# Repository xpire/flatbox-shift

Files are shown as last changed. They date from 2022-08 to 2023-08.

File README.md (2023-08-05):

# Hotbox: Low profile hitbox-layout fightstick
## This is a fork of Flatbox, where the PCB was modified to have a shift along with the directional inputs, and use hotswappable fullsize MX key switches

This repository contains 3D-printable models, PCB design files and code needed to make an arcade controller that looks like this:

Assembled Flatbox Shift
Look at the table for the difference between each revision.

Reddit post: https://www.reddit.com/r/fightsticks/comments/y1vh9n/my_custom_fight_stick_made_with_a_custom_pcb_7/

version | [rev1.1](hardware-rev1.1) | [rev2](hardware-rev2) | [rev3](hardware-rev3) | [rev4](hardware-rev4) | [shift](hardware-shift-rev2)
------- | ------------------------- | --------------------- | --------------------- | --------------------- | ----
case dimensions | 218x128x10mm | 218x130x10mm | 218x130x10mm | 218x130x10mm | 227.14x120x?mm
compatibility (using provided firmware) | PC, PS3 | PC, PS3 | PC, PS3, PS4 | PC, PS3 | PC, PS3
add-on board | Arduino Pro Micro | - | [Brook PS3/PS4](https://www.brookaccessory.com/detail/58690501/) | - | Arduino Pro Micro
onboard chip | - | ATmega32U4 | - | RP2040 | - 
port | micro USB | USB-C | USB-C | USB-C | USB-C (there are pro micros with usb c)
SMT assembly required | no | yes | yes | yes | no
firmware | [ATmega32U4](firmware-atmega32u4) | [ATmega32U4](firmware-atmega32u4) | [Brook](https://www.brookaccessory.com/download/PS3/) | [RP2040](firmware-rp2040) | [ATmega32U4](firmware-atmega32u4)
shift key | no | no | no | no | ***yes!***
key switches | low profile | low profile | low profile | low profile | ***normal MX***
hot swappable | yes | yes | yes | yes | yes
solder-able | yes | yes | yes | yes | no

# Process

## Design and Planning

First, we used Kicad to edit this existing PCB layout, adding an extra button for shift and swapping out the low profile gaterons for full sized MX hotswap.

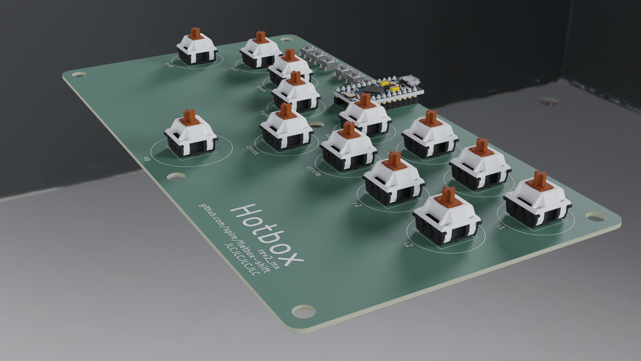
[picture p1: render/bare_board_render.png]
PCB Render


We then designed acrylic layers to encase the PCB, and mocked it in blender to see if it would work out.

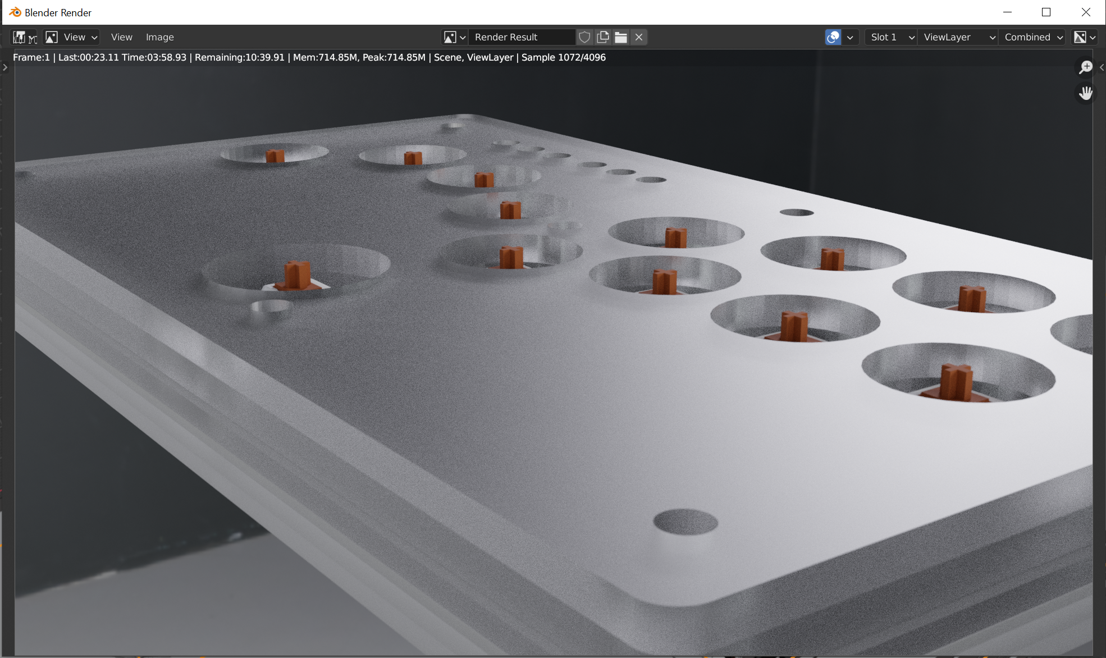
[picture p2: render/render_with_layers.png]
Acrylic Layers Render


## Prototyping

We printed the boards with https://jlcpcb.com/

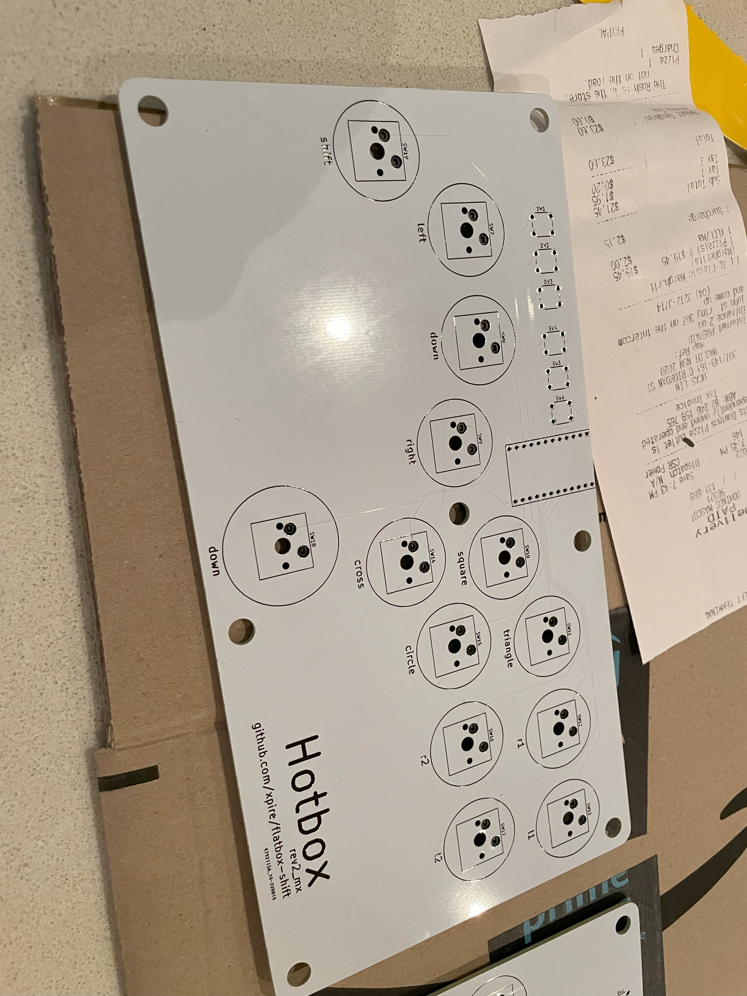
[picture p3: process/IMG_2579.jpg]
PCB IRL


We soldered on the arduino, and tested that the inputs worked

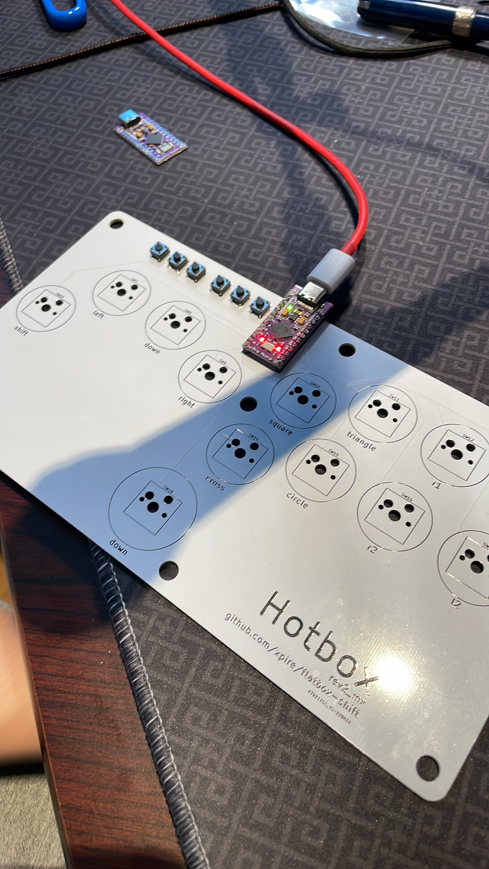
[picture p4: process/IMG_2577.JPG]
first test


Once we had verified the board worked, we 3D printed the layers to simulate what the final product would look like.

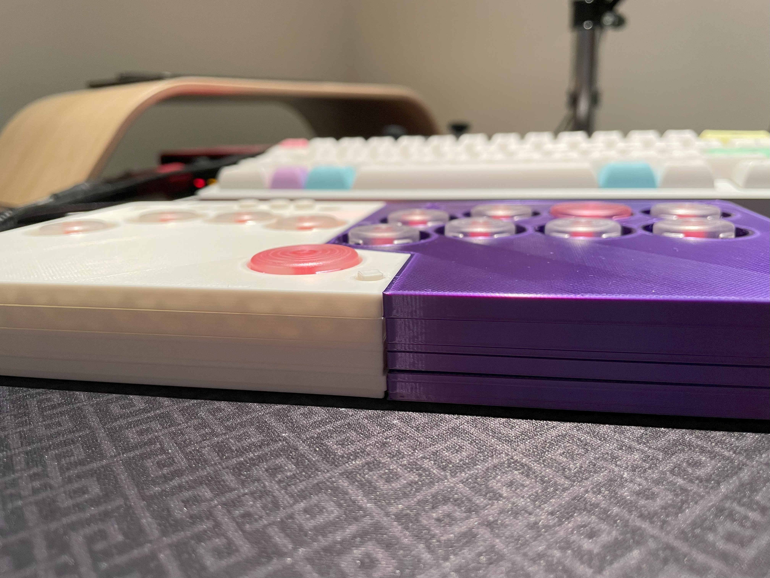
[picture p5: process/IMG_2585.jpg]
3d printed


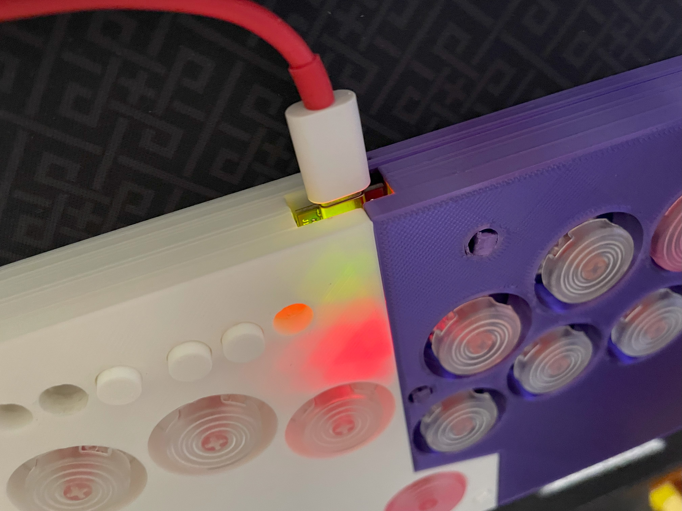
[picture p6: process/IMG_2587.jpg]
3d printed 2


## Fabrication

We borrowed a friend's uncle's CNC machine, and started carving the design out of sheets of acrylic.

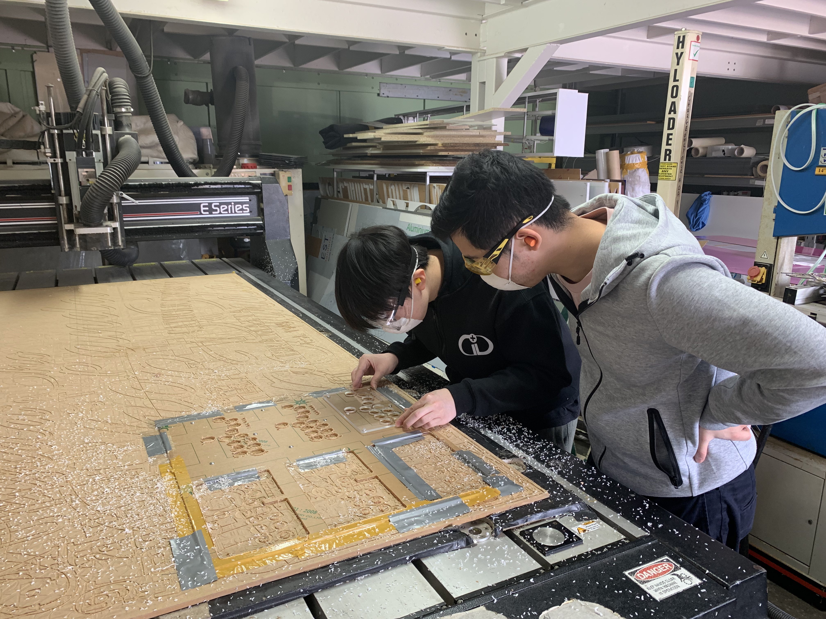
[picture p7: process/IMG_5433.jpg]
CNC 1


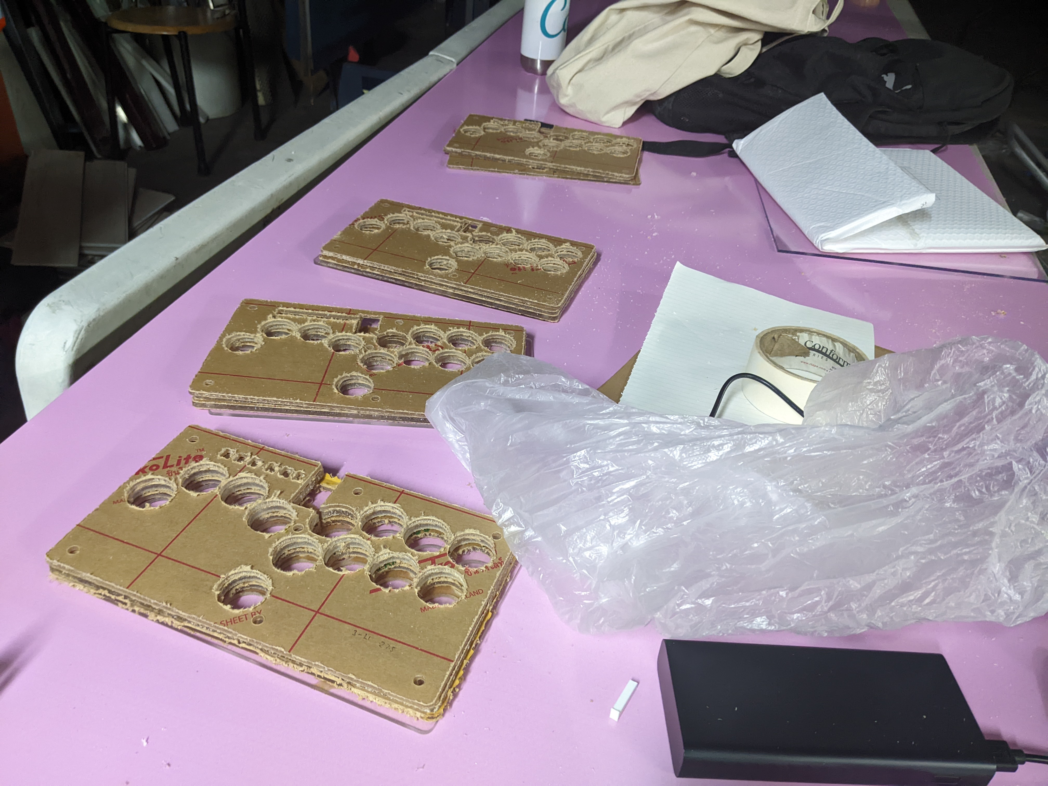
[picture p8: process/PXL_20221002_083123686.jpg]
CNC 2


## Result

front
Back
side
back2
stickers1
stickers2
stickers3

## Parts List
* arcade MX buttons - https://www.ebay.com/itm/165134564232 (url is now https://www.ebay.com/itm/155628299989)
* Chicago Screws - https://www.ebay.com/itm/0-67-034-to-0-87-034-17mm-to-22-mm-x-5mm-Stainless-steel-Knife-Handle-chicago-Screw-/231976520482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
* MX Switches
* Gateron hotswaps
* mini buttons
* Arduino pro micro with usb c
* Acrylic Layers (laser cut, or CNCed)

## Useful guides
- https://github.com/b1nc/Egg-On-Rice-Controller
- https://www.youtube.com/watch?v=ia2n7P3Csac

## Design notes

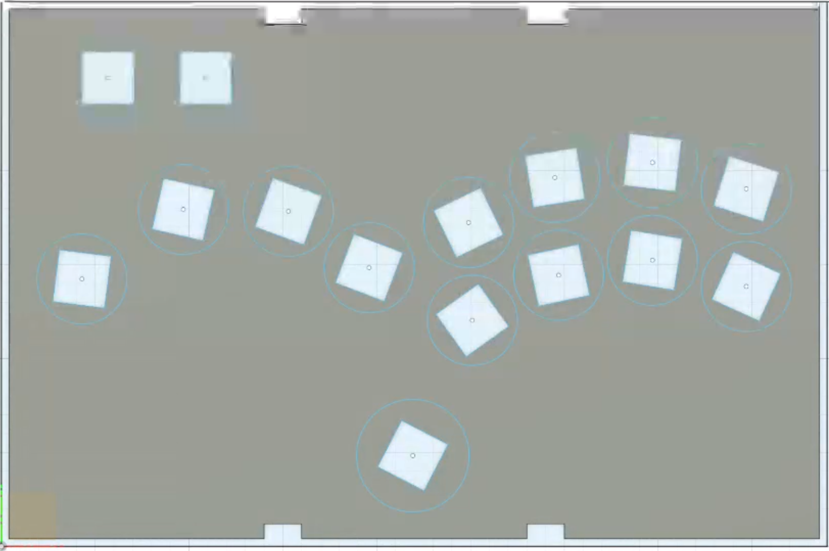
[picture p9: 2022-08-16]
hardware-shift-rev2/images/rough sketch.png

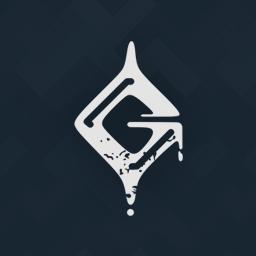
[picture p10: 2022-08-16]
hardware-shift-rev2/images/strive.jpg

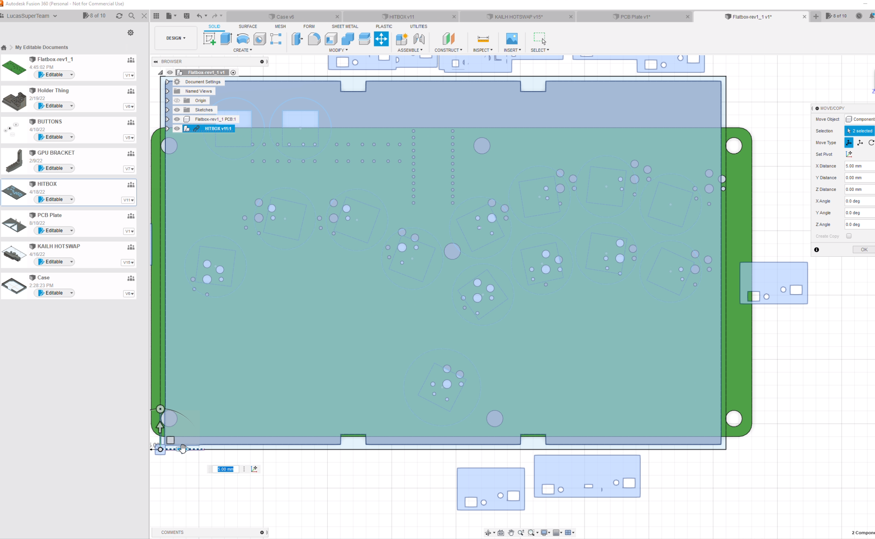
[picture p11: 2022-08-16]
hardware-shift-rev2/images/lucas vs current.png

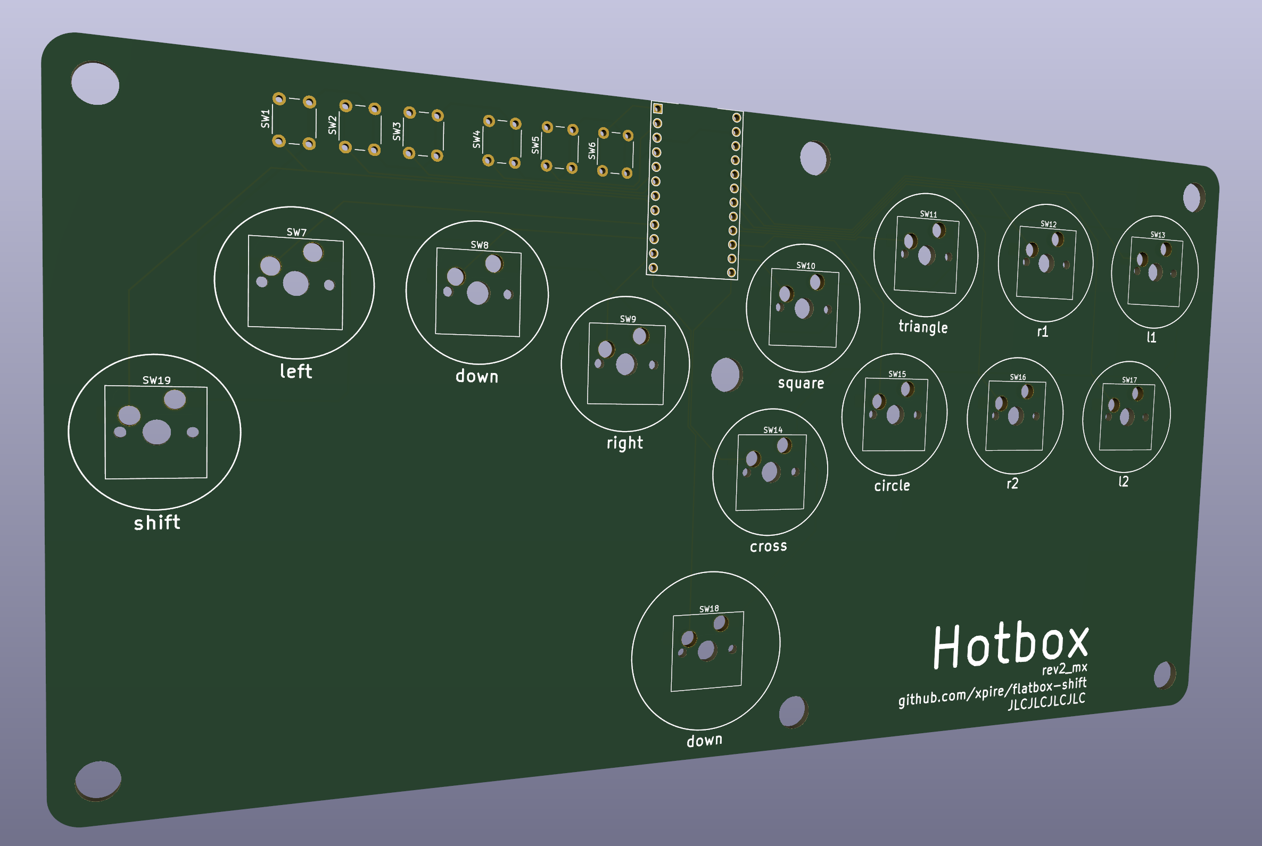
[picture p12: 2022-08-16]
hardware-shift-rev2/images/reference_pic.png

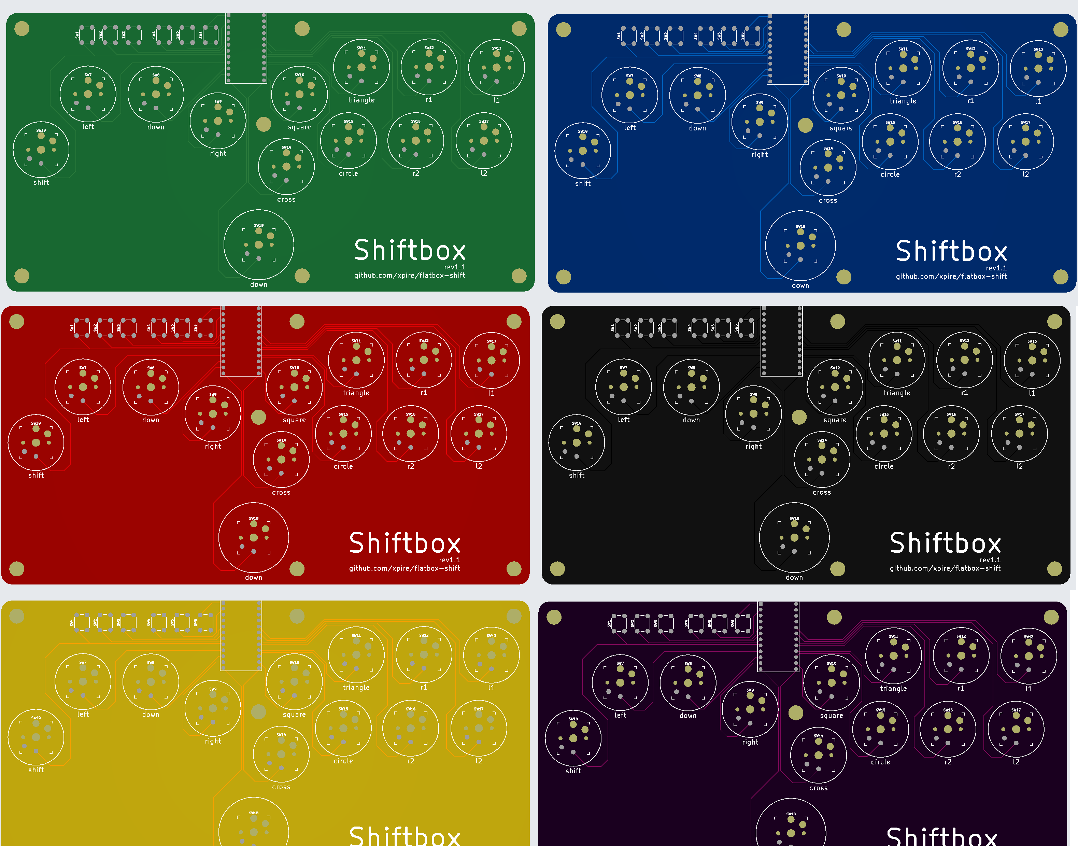
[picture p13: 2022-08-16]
hardware-shift-rev2/images/colorways.png

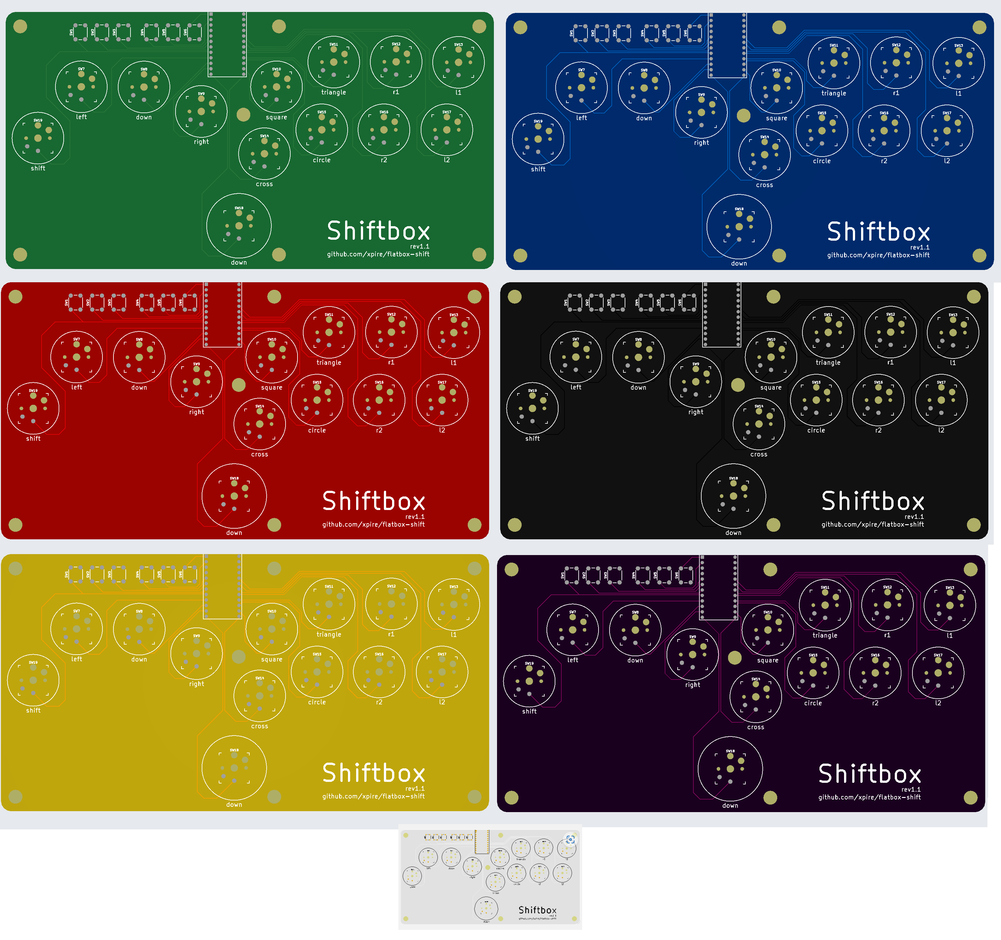
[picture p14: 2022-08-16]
hardware-shift-rev2/images/colorways-fixed.png

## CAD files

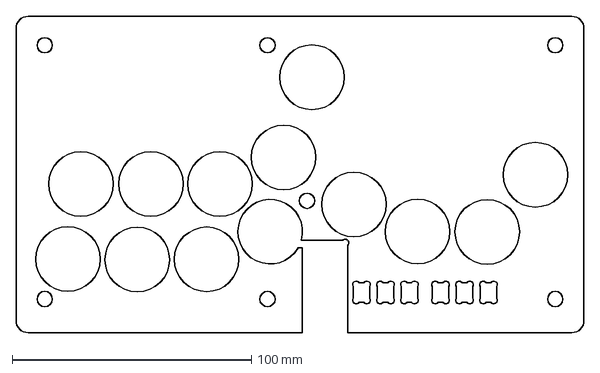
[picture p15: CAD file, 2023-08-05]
hardware-shift-rev2/acrylic/3_4.5mm.dxf
237.1 x 132.0 mm

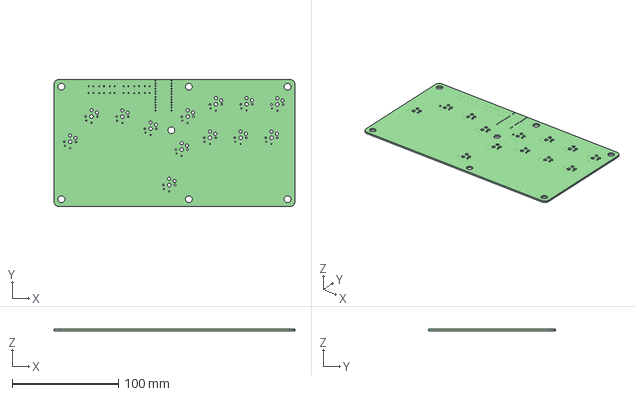
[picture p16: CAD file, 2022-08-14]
hardware-shift-rev2/extras/Flatbox-rev1.1-kicad/Flatbox-rev1_1.step
227.1 x 120.0 x 1.60 mm

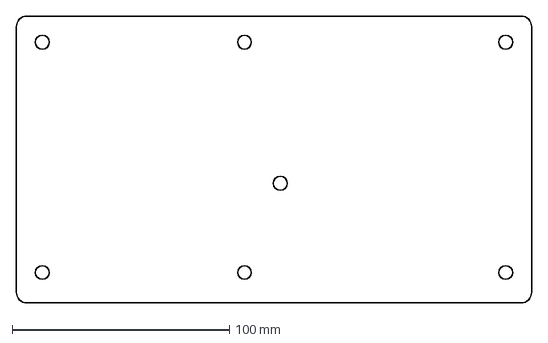
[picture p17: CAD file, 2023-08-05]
hardware-shift-rev2/acrylic/-2_1.5mm.dxf
237.1 x 132.0 mm

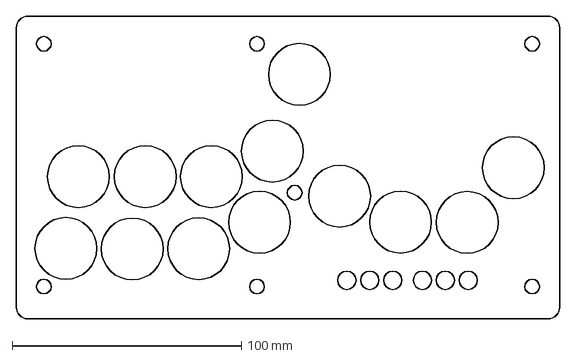
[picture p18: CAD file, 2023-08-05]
hardware-shift-rev2/acrylic/4_4.5mm.dxf
237.1 x 132.0 mm

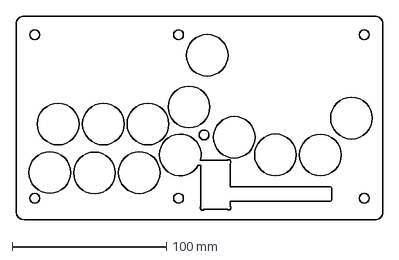
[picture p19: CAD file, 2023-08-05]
hardware-shift-rev2/acrylic/-1_3mm.dxf
237.1 x 132.0 mm

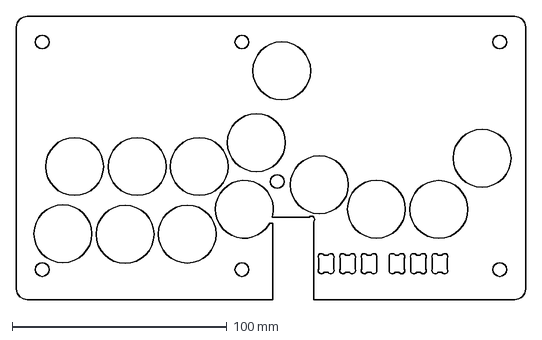
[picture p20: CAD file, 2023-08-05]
hardware-shift-rev2/acrylic/1_3.5mm.dxf
237.1 x 132.0 mm

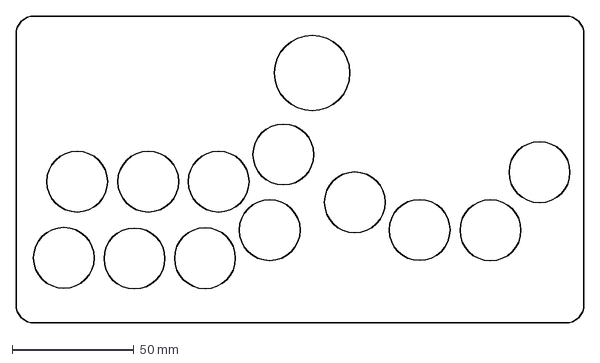
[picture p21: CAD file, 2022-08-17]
hardware-shift-rev2/acrylic/layer1.dxf
233.1 x 126.0 mm

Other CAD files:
hardware-shift-rev2/extras/Flatbox-rev2_mx.step

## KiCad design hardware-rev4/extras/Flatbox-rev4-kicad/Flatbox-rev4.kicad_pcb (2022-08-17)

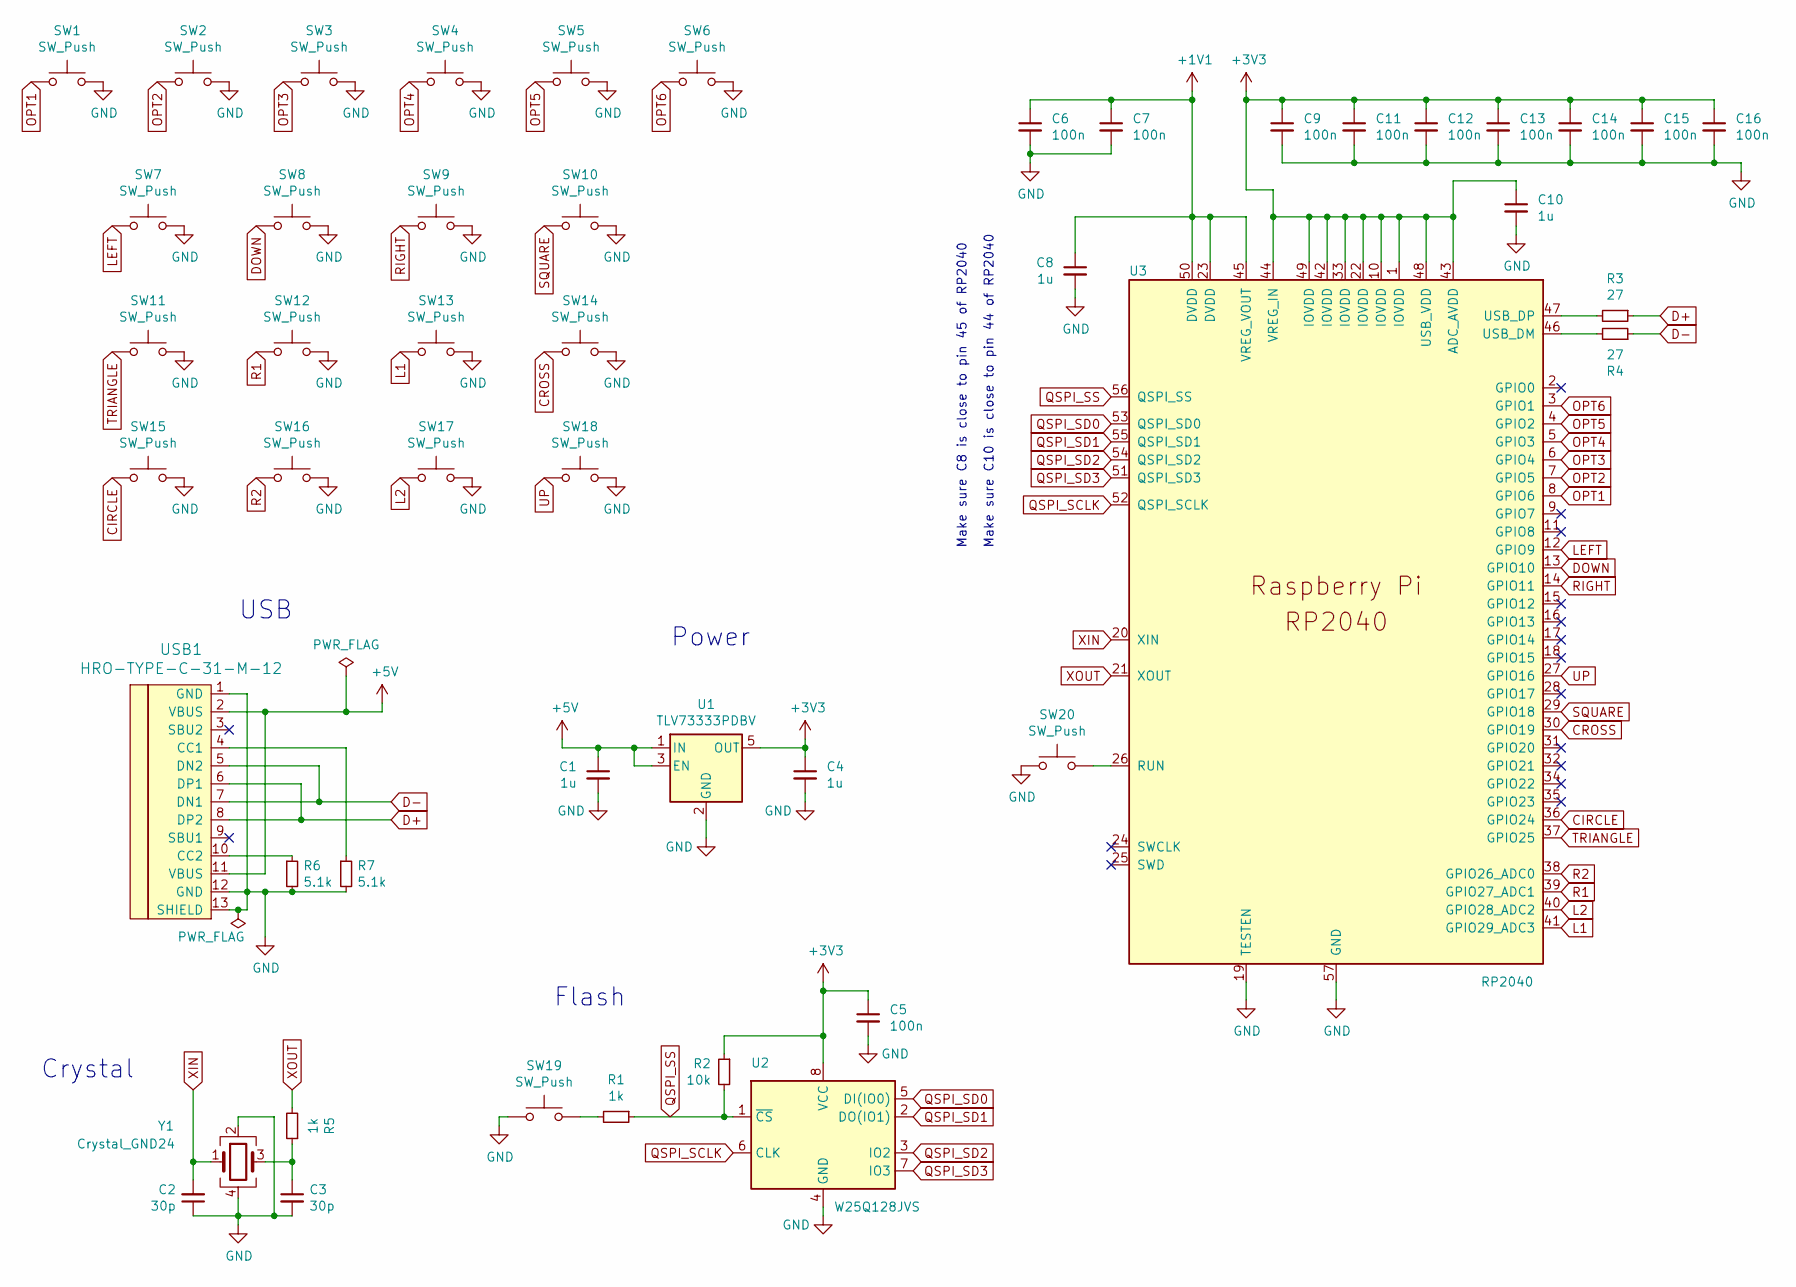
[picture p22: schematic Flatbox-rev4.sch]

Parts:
C1, C4, C8, C10: 1u; C_0402_1005Metric; LCSC C52923
C2, C3: 30p; C_0402_1005Metric; LCSC C1570
C5, C6, C7, C9, C11, C12, C13, C14, C15, C16: 100n; C_0402_1005Metric; LCSC C1525
R1, R5: 1k; R_0402_1005Metric; LCSC C11702
R2: 10k; R_0402_1005Metric; LCSC C25744
R3, R4: 27; R_0402_1005Metric; LCSC C138021
R6, R7: 5.1k; R_0402_1005Metric; LCSC C25905
SW1, SW2, SW3, SW4, SW5, SW6: SW_Push; SW_PUSH_6mm_H5mm
SW7, SW8, SW9, SW10, SW11, SW12, SW13, SW14, SW15, SW16, SW17, SW18: SW_Push; Kailh_socket_PG1350_optional
SW19, SW20: SW_Push; SW_SPST_Omron_B3FS-100xP; LCSC C271750
U1: TLV73333PDBV; SOT-23-5; LCSC C134139
U2: W25Q128JVS; SOIC-8_5.23x5.23mm_P1.27mm; LCSC C97521
U3: RP2040; RP2040-QFN-56; LCSC C2040
USB1: HRO-TYPE-C-31-M-12; HRO-TYPE-C-31-M-12-Assembly; LCSC C165948
Y1: Crystal_GND24; Crystal_SMD_3225-4Pin_3.2x2.5mm; LCSC C9002

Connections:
+1V1: C6.1, C7.1, C8.1, U3.23 (DVDD), U3.45 (VREG_VOUT), U3.50 (DVDD)
+3V3: C4.1, C5.1, C9.1, C10.1, C11.1, C12.1, C13.1, C14.1, C15.1, C16.1, R2.1, U1.5 (OUT), U2.8 (VCC), U3.1 (IOVDD), U3.10 (IOVDD), U3.22 (IOVDD), U3.33 (IOVDD), U3.42 (IOVDD), U3.43 (ADC_AVDD), U3.44 (VREG_IN), U3.48 (USB_VDD), U3.49 (IOVDD)
+5V: C1.1, U1.1 (IN), U1.3 (EN), USB1.2 (VBUS), USB1.11 (VBUS)
CIRCLE: SW15.1, U3.36 (GPIO24)
CROSS: SW14.1, U3.30 (GPIO19)
D+: R3.1, USB1.6 (DP1), USB1.8 (DP2)
D-: R4.1, USB1.5 (DN2), USB1.7 (DN1)
DOWN: SW8.1, U3.13 (GPIO10)
GND: C1.2, C2.1, C3.2, C4.2, C5.2, C6.2, C7.2, C8.2, C9.2, C10.2, C11.2, C12.2, C13.2, C14.2, C15.2, C16.2, R6.2, R7.2, SW1.2, SW2.2, SW3.2, SW4.2, SW5.2, SW6.2, SW7.2, SW8.2, SW9.2, SW10.2, SW11.2, SW12.2, SW13.2, SW14.2, SW15.2, SW16.2, SW17.2, SW18.2, SW19.1, SW20.1, U1.2 (GND), U2.4 (GND), U3.19 (TESTEN), U3.57 (GND), USB1.1 (GND), USB1.12 (GND), USB1.13 (SHIELD), Y1.2, Y1.4
L1: SW13.1, U3.41 (GPIO29_ADC3)
L2: SW17.1, U3.40 (GPIO28_ADC2)
LEFT: SW7.1, U3.12 (GPIO9)
unnamed: C3.1, R5.1, Y1.3
unnamed: R1.2, SW19.2
unnamed: R3.2, U3.47 (USB_DP)
unnamed: R4.2, U3.46 (USB_DM)
unnamed: R6.1, USB1.10 (CC2)
unnamed: R7.1, USB1.4 (CC1)
unnamed: SW20.2, U3.26 (RUN)
OPT1: SW1.1, U3.8 (GPIO6)
OPT2: SW2.1, U3.7 (GPIO5)
OPT3: SW3.1, U3.6 (GPIO4)
OPT4: SW4.1, U3.5 (GPIO3)
OPT5: SW5.1, U3.4 (GPIO2)
OPT6: SW6.1, U3.3 (GPIO1)
QSPI_SCLK: U2.6 (CLK), U3.52 (QSPI_SCLK)
QSPI_SD0: U2.5 (DI(IO0)), U3.53 (QSPI_SD0)
QSPI_SD1: U2.2 (DO(IO1)), U3.55 (QSPI_SD1)
QSPI_SD2: U2.3 (IO2), U3.54 (QSPI_SD2)
QSPI_SD3: U2.7 (IO3), U3.51 (QSPI_SD3)
QSPI_SS: R1.1, R2.2, U2.1 (~CS), U3.56 (QSPI_SS)
R1: SW12.1, U3.39 (GPIO27_ADC1)
R2: SW16.1, U3.38 (GPIO26_ADC0)
RIGHT: SW9.1, U3.14 (GPIO11)
SQUARE: SW10.1, U3.29 (GPIO18)
TRIANGLE: SW11.1, U3.37 (GPIO25)
UP: SW18.1, U3.27 (GPIO16)
XIN: C2.2, U3.20 (XIN), Y1.1
XOUT: R5.2, U3.21 (XOUT)

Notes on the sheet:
Make sure C10 is close to pin 44 of RP2040
Crystal
Power
USB
Make sure C8 is close to pin 45 of RP2040
Flash

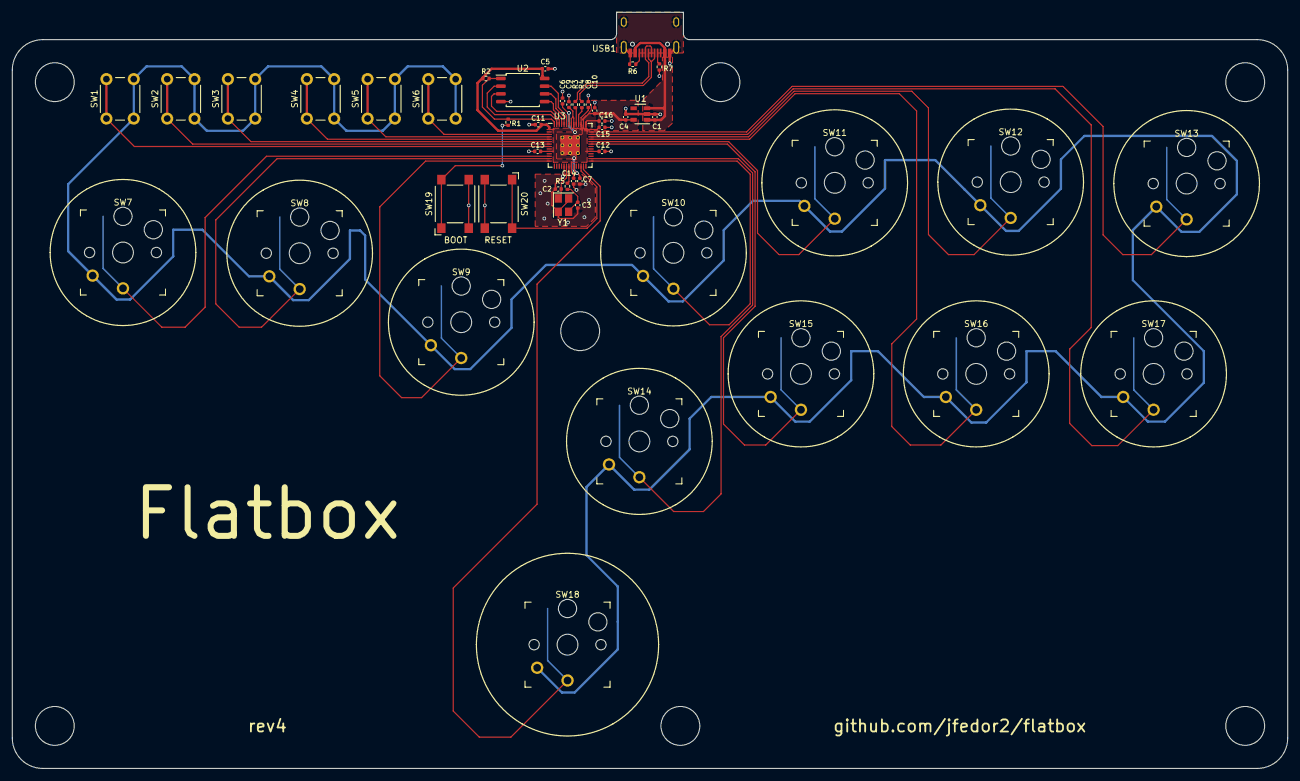
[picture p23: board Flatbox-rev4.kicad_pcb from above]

Board: 2 copper layers, 210.0 x 124.5 mm, 48 parts (0 on the bottom side), 39 nets.

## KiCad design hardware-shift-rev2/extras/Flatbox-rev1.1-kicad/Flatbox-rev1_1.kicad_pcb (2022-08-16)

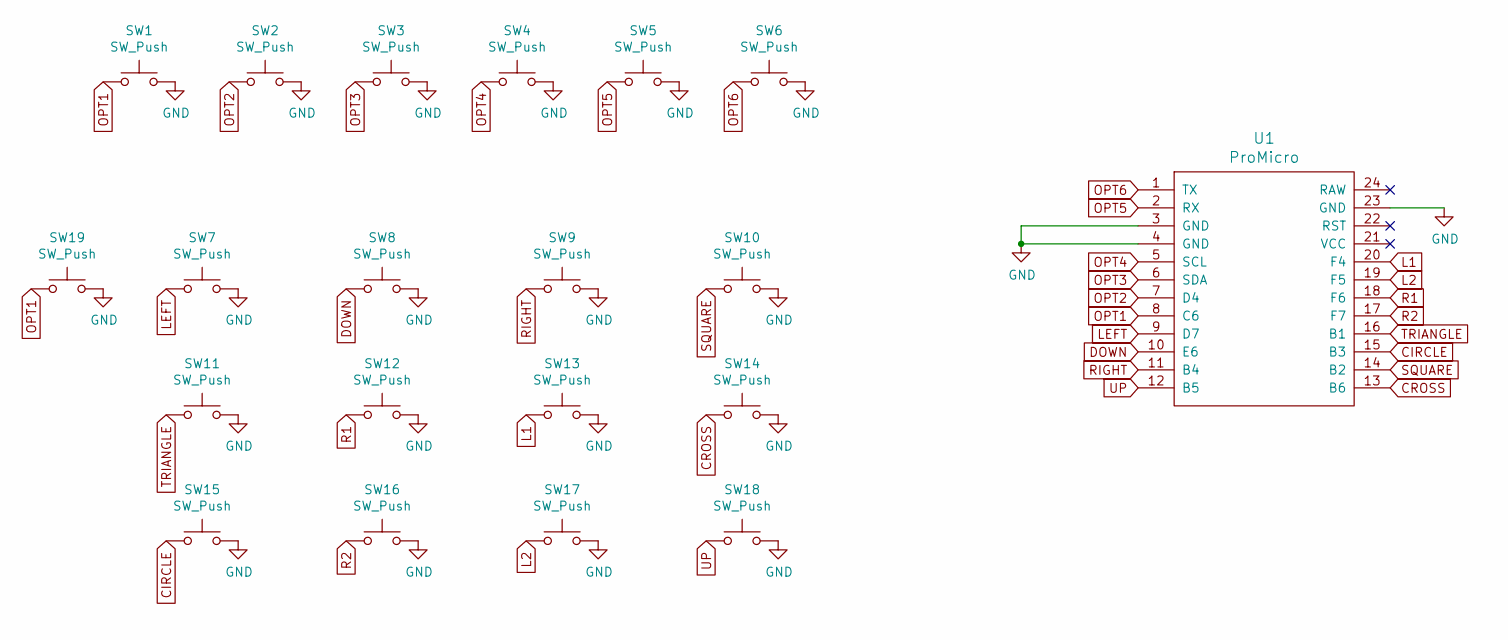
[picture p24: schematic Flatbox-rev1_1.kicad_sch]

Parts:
SW1, SW2, SW3, SW4, SW5, SW6: SW_Push; SW_PUSH_6mm_H5mm
SW7, SW8, SW9, SW10, SW11, SW12, SW13, SW14, SW15, SW16, SW17, SW18, SW19: SW_Push; SW_Hotswap_Kailh_MX_plated_1.00u
U1: ProMicro

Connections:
CIRCLE: SW15.1, U1.15 (B3)
CROSS: SW14.1, U1.13 (B6)
DOWN: SW8.1, U1.10 (E6)
GND: SW1.2, SW2.2, SW3.2, SW4.2, SW5.2, SW6.2, SW7.2, SW8.2, SW9.2, SW10.2, SW11.2, SW12.2, SW13.2, SW14.2, SW15.2, SW16.2, SW17.2, SW18.2, SW19.2, U1.3 (GND), U1.4 (GND), U1.23 (GND)
L1: SW13.1, U1.20 (F4)
L2: SW17.1, U1.19 (F5)
LEFT: SW7.1, U1.9 (D7)
OPT1: SW1.1, SW19.1, U1.8 (C6)
OPT2: SW2.1, U1.7 (D4)
OPT3: SW3.1, U1.6 (SDA)
OPT4: SW4.1, U1.5 (SCL)
OPT5: SW5.1, U1.2 (RX)
OPT6: SW6.1, U1.1 (TX)
R1: SW12.1, U1.18 (F6)
R2: SW16.1, U1.17 (F7)
RIGHT: SW9.1, U1.11 (B4)
SQUARE: SW10.1, U1.14 (B2)
TRIANGLE: SW11.1, U1.16 (B1)
UP: SW18.1, U1.12 (B5)

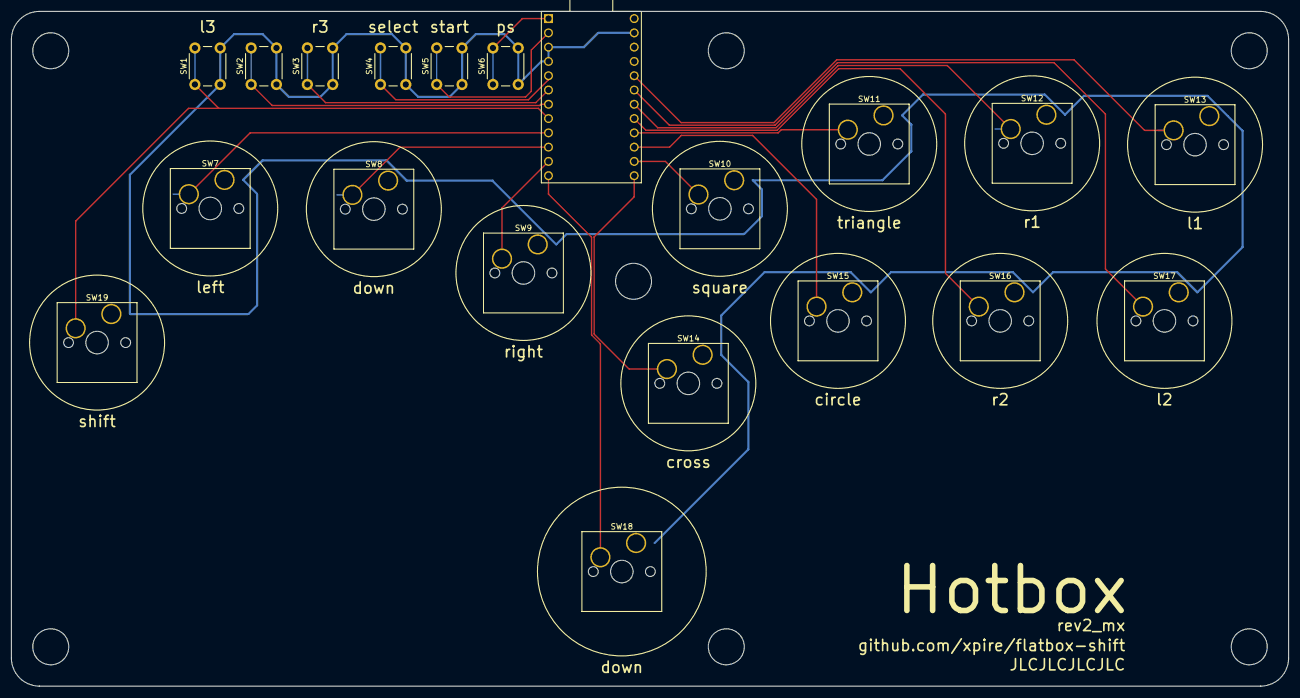
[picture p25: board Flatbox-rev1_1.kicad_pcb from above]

Board: 2 copper layers, 227.1 x 120.0 mm, 20 parts (0 on the bottom side), 19 nets.

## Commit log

2022-08-14 modify pcb with left shift
    [Flatbox-rev1_1.kicad_pcb, Flatbox-rev1_1.kicad_sch, Flatbox-rev1_1.sch]
2022-08-14 new version with modified action keys and parallel R3/shift
    [Flatbox-rev1_1-B_Cu.gbl, Flatbox-rev1_1-B_Mask.gbs, Flatbox-rev1_1-B_Paste.gbp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]
2022-08-14 parallel action keys
    [Flatbox-rev1_1.kicad_pcb]
2022-08-14 3rd action keys up, top by 3mm, bottom by 4mm
    [Flatbox-rev1_1.kicad_pcb]
2022-08-14 smaller tolerance tilted
    [Flatbox-rev1_1.kicad_pcb]
2022-08-14 added key labels
    [Flatbox-rev1_1.kicad_pcb]
2022-08-14 no wires rev2 (please position now)
    [Flatbox-rev1_1.kicad_pcb, Flatbox-rev1_1.kicad_sch, Flatbox-rev1_1.sch]
2022-08-14 minimal changes should work 100% because i changed literally nothing
    [Flatbox-rev1_1.kicad_pcb, Flatbox-rev1_1.step]
2022-08-16 finalised MX compatiable hotswap pcb
    [Flatbox-rev1_1-B_Cu.gbl, Flatbox-rev1_1-B_Mask.gbs, Flatbox-rev1_1-B_Paste.gbp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]
2022-08-16 step file uploaded
    [Flatbox-rev2_mx.step]
2022-08-17 Add layer1.dxf
    [layer1.dxf]
2022-08-17 clean up folders
    [Flatbox-rev1_1-B_Cu.gbl, Flatbox-rev1_1-B_Mask.gbs, Flatbox-rev1_1-B_Paste.gbp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]
2022-08-17 Remove random arc
    [layer1.dxf]
2023-08-05 Add layers and pictures of construction
    [-1_3mm.dxf, -2_1.5mm.dxf, 1_3.5mm.dxf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]
